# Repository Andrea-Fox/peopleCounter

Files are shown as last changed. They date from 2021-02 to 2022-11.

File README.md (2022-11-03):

# This folder is currently archived

----------------------------------------------------------

# ESP people counter

This repository contains a program (to be flashed, for example on an ESP32, using the Arduino IDE) which allows to create a sensor capable of detecting people going in and out of a room. It works using the VL53L1X sensor by ST Microelectronics. The passage detection is then shared through the MQTT protocol and the count of the people in the room is done directly on other platform such as Home Assistant (see the dedicated file for a smooth integration in Home Assistant).

## Idea behind the algorithm

The code contains an adaptation of the program  [STSW-IMG10](https://www.st.com/en/embedded-software/stsw-img010.html) (developed by ST Microelectronics), written using the [Sparkfun library for VL53L31X](https://learn.sparkfun.com/tutorials/qwiic-distance-sensor-vl53l1x-hookup-guide/all).  

**The library used is from SparkFun and is made for [their sensor](https://www.sparkfun.com/products/14722), however the same code can also be used alongside the [Pololu VL53L31X sensor](https://www.pololu.com/product/3415).**

The sensor uses the time of flight (ToF) of invisible, eye-safe laser pulses to measure absolute distances independent of ambient lighting conditions  and target characteristics like color, shape, and texture (though these  things will affect the maximum range).  Something is detected in a certain zone, when the distance read by the sensor os lower than the corresponding threshold. 

The idea behind the main algorithm counting for people is the following: after defining two different zones, a passage (entrance or exit) is registered only when:

1. a person is detected in the first zone
2. a person is detected in both zones simultaneously
3. a person is detected in the second zone
4. no person are detected in both zones

Then, depending on which are the first and the second zone, the movement will be either registered as an entrance or an exit. 

## Hardware

### Sensor

As previously stated, the library used to write the code is built for the [Sparkfun Distance Sensor](https://www.sparkfun.com/products/14722), but also works using the [Pololu VL53L31X sensor](https://www.pololu.com/product/3415).
It probably should also work with other VL53L1X sensors, however I've never tried it.

### Board

The following tables contain the necessary wire connections, when using certain boards.

#### 5V boards

(including Arduino Uno, Leonardo, Mega)

```
Arduino   VL53L1X board
-------   -------------
     5V - VIN
    GND - GND
    SDA - SDA
    SCL - SCL
```

The Pololu sensor can also be connetced to 3.3V boards, such as the Arduino Due.

Clearly, to use the MQTT functionalities one has to use a board which supports WiFi connection, such as ESP32: in this case, the connections are the following:

#### ESP32

```
                    ESP32   VL53L1X board
-------------------------   -------------
                      3V3 - VIN
                      GND - GND
     SDA (pin 42, GPIO21) - SDA
     SCL (pin 39, GPIO22) - SCL
```
The sensors from Pololu and Adafruit can also be connected to the 5v pin (VIN)
#### ESP8266
It is also possible to use an ESP8266, using, for example, the following connections: (in that case, use the code specific for this board)
```
                  ESP8266   VL53L1X board
-------------------------   -------------
                      3V3 - VIN
                      GND - GND
                       D2 - SDA
                       D1 - SCL
```

## How to adapt the code to your case

The sensor can be mounted on the top of a door frame or on the side. It has been observed that if the door is wide it is more convenient to mount the sensor on the side.

### WiFi information

In order to connect to the WiFi, one has to specify the name of the WiFi network, its password, the MQTT broker address and ots port, the MQTT username and the corresponding password. All this values have to inserted at the beginning of the code, in the corresponding lines.

### Parameters one might want to set

In the first few lines of the code in the main folder, there are a few parameters which can be modified: (in the parentheses, are indicated the default values)

- `devicename` (name_for_this_device)
- `threshold_percentage` (80)
- `update_raw_measurements` (false)
- `advised_orientation_of_the_sensor` (true)
- `save_calibration_result` (true)
- `short_distance_threshold` (1300)
- `delay_between_measurements_long` (50)
- `time_budget_in_ms_long` (50)
- `delay_between_measurements_short` (20)
- `time_budget_in_ms_short` (20)

Some parameters areavailable only in the ESP32 version. 

#### Name of the device
It indicates the room in which the sensor is going to be positioned. It will simplt change the MQTT topics and will help when multiple sensors are placed around the house.

#### Threshold percentage

After mounting the sensor, it detects automatically the height at which it is situated. When the sensor is working, a person is detected if the distance measured is below a certain threshold, hence defining the right thresholds is pivotal to guarantee a correct functioning of the whole system. It has been observed that having as threshold a value which is 80% of the distance measured in general produces good results, however one might observe that is his sistuation another value of the threshold is better.

#### Update raw measurements
In the initial phase, or when debugging, it can be useful to read the distance measured every 100 ms by the sensor, however in general thish is not useful and produces an useless cinsumption of the resources.
This value has to be set to true if one wants to read the distances measured, however the advice is to hold that to `false`.  
One can change this value through MQTT using the command "update_raw_measurement".

#### Advised orientation of the sensor
This value is going to deterin the center of each zone of detection and has to be true if the sensor is positioned as in the following image:
<p float="left">
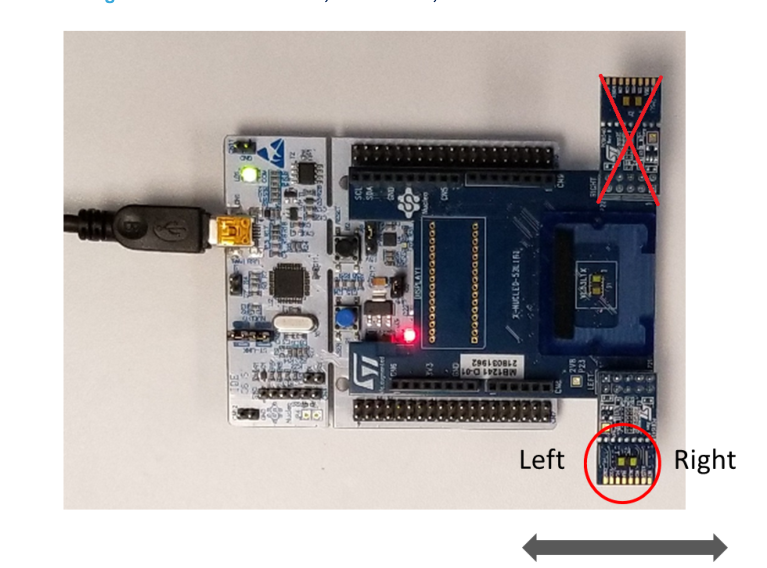
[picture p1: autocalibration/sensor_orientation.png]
  
</p>

The arrow indicates the direction of the people passing under the sensor.

#### Save calibration result
If this value is true, then the results of the calibration of the zones are going to be stored in the EEPROM memory, hence if the ESP is turned off no data is going to be lost. If false, every time the sensor is turned on, a new calibraion is launched, however that is useless if the sensor is always in the same position.
A recalibration can still be called using the MQTT command (see the integration with Home Assistant file)

#### Short distance threshold
When the distane measured in one of the zones is below this threshold (exoressed in millimeters) the sensor uses the short distance mode, which allows more frequent measurements and better performances. The VL53L1X sensor supports short distance mode only if the distance is below 1300 mm

#### Measurements time parameters
These parameters set the time the sensor takes to do a measurements (in milliseconds) and the following delay between two different measurements. The user can define two different values: one for the longRange mode and one for the shortRange mode

### Additional information

Additional information about the parameters used in the code can be found in the `additional_information.md` file in the `manual_configuration` folder

### How to invert the two zones
If you observe that when you get in a room the number of people inside it decreases, while it increases when you get out it means that the values of the centers are inverted. to solve this issue, you can simply invert the values 1 and 2 in the automations which regulate the number of people in the `integration_with_home_assistant.md` file.

### Issues due to sunlight
As stated in the datasheet from the creators of the sensor, the VL53L1X has (much) less accuracy when there is a lot of light. Unfortunately it is not possible to eliminate such issue

## Case for the sensor

In the `case` folder you can find an several stl files created by @noxhirsch for a case that fits both the ESP and the VL53L1X sensor.

## Discord server

If you want to discuss about the idea of finding the ultimate room presence sensor, feel free to join the dedicate Discord server, created by @DutchDeffy: https://discord.gg/65eBamz7AS

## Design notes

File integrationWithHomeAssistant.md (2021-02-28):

# Integration with the Home Assistant
These example of automations are based on the topics defined in the file with automatic calibration called either `people_counter_esp32.ino` or `people_counter_esp8266`. If you are using the file in the `manual calibration` folder, you will have to change the topics.

In order to integrate this sensor inside your Home Assistant setup, the following chunks of code need to be added to the appropriate files.

**We will have to define an input number**, that simply will count the number of people inside the room. It will be called `input_number.people_in_the_room`

The parameter DEVICENAME has to be set in the code, at the beginning of it.

#### automations.yaml

We now need to define two automations that will allow us to understand when someone is getting in or out of the room. This first one will take account of the first case.

```yaml
- alias: 'Person entering the room'
  description: ''
  id: 'person_entering_the_room' # unique id here
  trigger:
     - platform: mqtt
       topic: "people_counter/DEVICENAME/counter"
       payload: '1'
  action:
     - service: input_number.increment
       data: 
            entity_id: input_number.people_in_the_room
  mode: single

```

The following automation will take account of the case of someone exiting the room:

```yaml
- alias: 'Person exiting the room'
  description: ''
  id: 'person_exiting_the_room' # unique id here
  trigger:
     - platform: mqtt
       topic: "people_counter/DEVICENAME/counter"
       payload: '2'
  action:
     - service: input_number.decrement
       data: 
            entity_id: input_number.people_in_the_room
  mode: single

```

If you are using a version of HA >=113.0, you can use only the followning automation (suggested by @noxhirsch) to handle the number of people in the room:
```yaml
alias: Person Counter
trigger:
  - platform: mqtt
    topic: people_counter/DEVICENAME/counter
action:
  - choose:
      - conditions:
          - condition: template
            value_template: '{{ trigger.payload == "1" }}'
        sequence:
          - service: input_number.increment
            entity_id: input_number.people_counter
      - conditions:
          - condition: template
            value_template: '{{ trigger.payload == "2" }}'
        sequence:
          - service: input_number.decrement
            entity_id: input_number.people_counter
mode: single
```

Finally, this automation will turn on a light when there is at least one person in the room:

```yaml
- alias: 'Turn on the light'
  description: ''
  id: 'turn_on_the_light' # unique id here
  trigger:
    - entity_id: input_number.people_in_the_room
      above: '0'
      platform: numeric_state
  action:
    - service: switch.turn_on
      entity_id: switch.light_in_the_room
  mode: single
```

and this one turns the light off when the last person gets out of the room:

```yaml
- alias: 'Turn on the light'
  description: ''
  id: 'turn_on_the_light' # unique id here
  trigger:
    - entity_id: input_number.people_in_the_room
      below: '1'
      platform: numeric_state
  action:
    - service: switch.turn_off
      entity_id: switch.light_in_the_room
  mode: single

```

One might also define an automation for recalibrating the thresholds every day at a certain time (let's say 4 am):
```yaml
- alias: 'Recalibrate threshold'
  description: ''
  id: 'recalibrate_threshold' # unique id here
  trigger:
    - at: '04:00:00'
      platform: time
  action:
    - service: mqtt.publish
      data:
        topic: people_counter/DEVICENAME/receiver
        payload_template: "new_threshold"
  mode: single

```

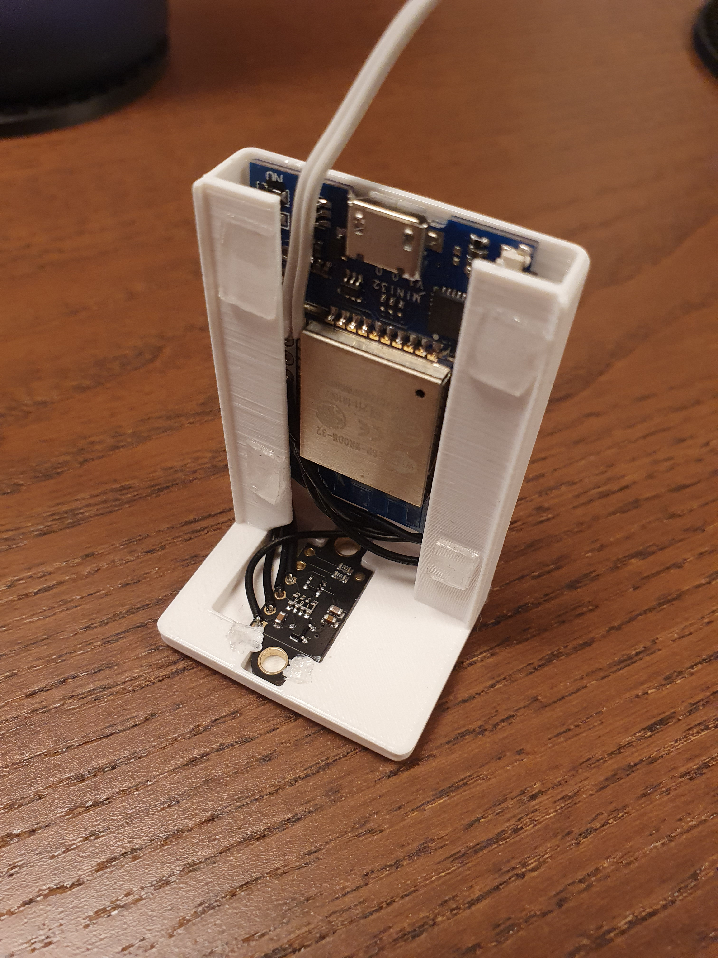
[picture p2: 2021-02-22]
case/case_image.jpg

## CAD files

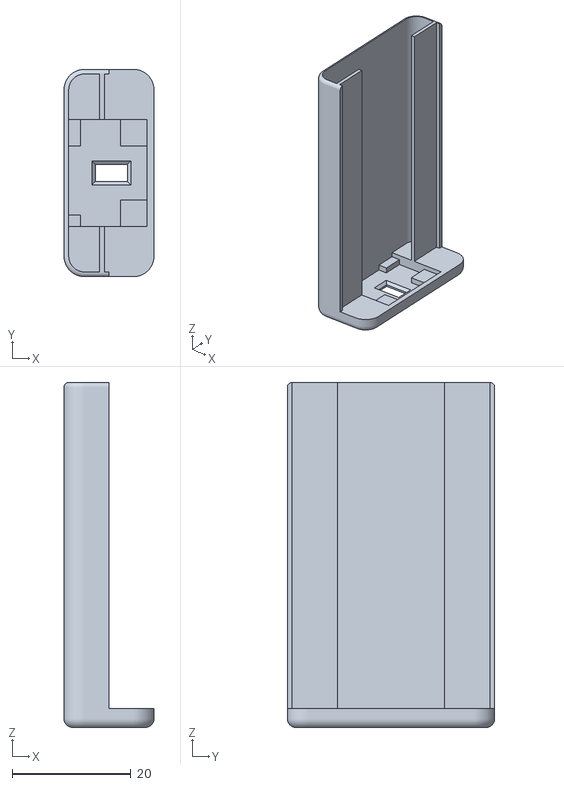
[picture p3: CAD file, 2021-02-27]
case/Person_Tracker_Pololu_Fat.stl
15.2 x 35.0 x 58.2

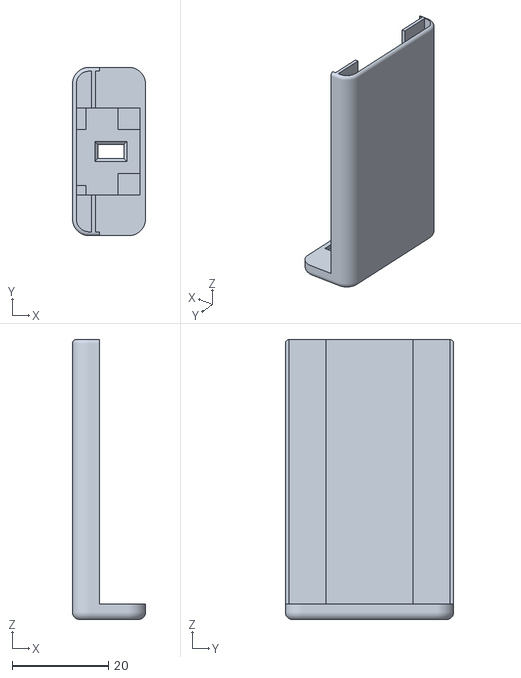
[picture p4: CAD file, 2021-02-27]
case/Person_Tracker_Pololu_Slim.stl
15.2 x 35.0 x 58.2

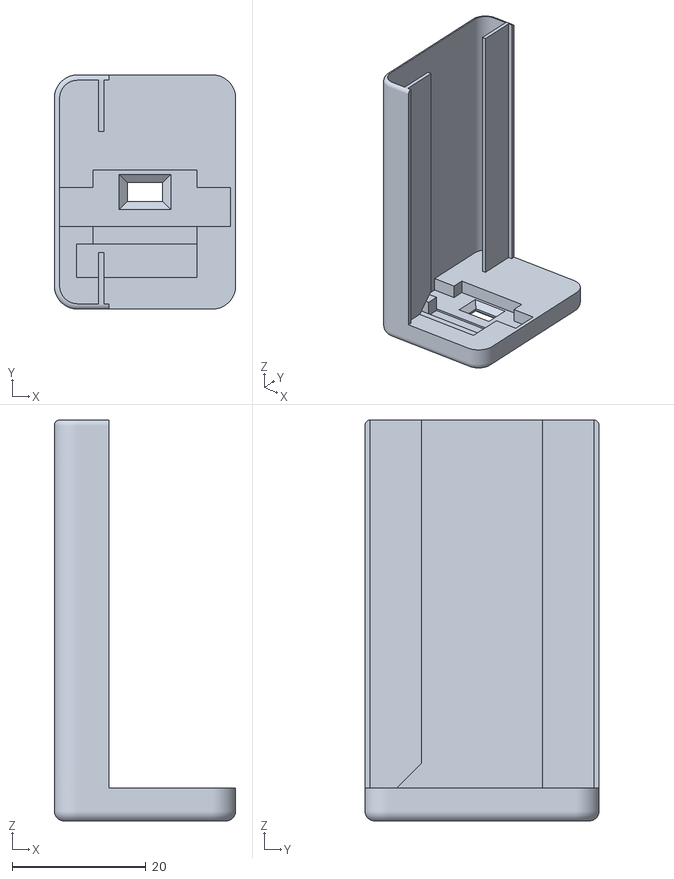
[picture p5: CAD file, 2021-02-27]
case/Person_Tracker_Aliexpress.stl
27.1 x 35.0 x 59.9

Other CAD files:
case/People Counter Aliexpress.f3d
case/People Counter Pololu.f3d

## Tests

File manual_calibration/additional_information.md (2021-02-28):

## Additional informations about the parameters

#### Relevant area

In order to find the correct distance, the sensor creates a 16x16 grid and the final distance is computed by taking the average of the distance of the values of the grid; to perform our task, one has to create two zones, by defining two different Region of Interest (ROI) inside this grid. Then the sensor will measure the two distances in the two zones and will detect any presence. 

However, the algorithm is very sensitive to the slightest modification of the ROI, regarding both its size and its positioning inside the grid.

In the original code, developed by ST Microelectronics, the values for the parameters are the following:

- `ROI_width = 8`
- `ROI_height = 16`
- `center = {167,231}`
however, I've noticed better performances with the values suggested in the code above.

Be careful that both `ROI_width` and `ROI_heigth` have to be at least 4. The center of the ROI you set is based on the table below and the optical center has to be set as the pad above and to the right of your exact center:

| 128  | 136  | 144  | 152  | 160  | 168  | 176  | 184  | 192  | 200  | 208  | 216  | 224  | 232  | 240  | 248  |
| ---- | ---- | ---- | ---- | ---- | ---- | ---- | ---- | ---- | ---- | ---- | ---- | ---- | ---- | ---- | ---- |
| 129  | 137  | 145  | 153  | 161  | 169  | 177  | 185  | 193  | 201  | 209  | 217  | 225  | 233  | 241  | 249  |
| 130  | 138  | 146  | 154  | 162  | 170  | 178  | 186  | 194  | 202  | 210  | 218  | 226  | 234  | 242  | 250  |
| 131  | 139  | 146  | 155  | 163  | 171  | 179  | 187  | 195  | 203  | 211  | 219  | 227  | 235  | 243  | 251  |
| 132  | 140  | 147  | 156  | 164  | 172  | 180  | 188  | 196  | 204  | 212  | 220  | 228  | 236  | 244  | 252  |
| 133  | 141  | 148  | 157  | 165  | 173  | 181  | 189  | 197  | 205  | 213  | 221  | 229  | 237  | 245  | 253  |
| 134  | 142  | 149  | 158  | 166  | 174  | 182  | 190  | 198  | 206  | 214  | 222  | 230  | 238  | 246  | 254  |
| 135  | 143  | 150  | 159  | 167  | 175  | 183  | 191  | 199  | 207  | 215  | 223  | 231  | 239  | 247  | 255  |
| 127  | 119  | 111  | 103  | 95 | 87 | 79 | 71 | 63 | 55 | 47 | 39 | 31 | 23 | 15 | 7 |
| 126  | 118  | 110  | 102  | 94 | 86 | 78 | 70 | 62 | 54 | 46 | 38 | 30 | 22 | 14 | 6 |
| 125  | 117  | 109  | 101  | 93 | 85 | 77 | 69 | 61 | 53 | 45 | 37 | 29 | 21 | 13 | 5 |
| 124  | 116  | 108  | 100  | 92 | 84 | 76 | 68 | 60 | 52 | 44 | 36 | 28 | 20 | 12 | 4 |
| 123  | 115  | 107  | 99 | 91 | 83 | 75 | 67 | 59 | 51 | 43 | 35 | 27 | 19 | 11 | 3 |
| 122  | 114  | 106  | 98 | 90 | 82 | 74 | 66 | 58 | 50 | 42 | 34 | 26 | 18 | 10 | 2 |
| 121  | 113  | 105  | 97 | 89 | 81 | 73 | 65 | 57 | 49 | 41 | 33 | 25 | 17 | 9 | 1 |
| 120  | 112  | 104  | 96 | 88 | 80 | 72 | 64 | 56 | 48 | 40 | 32 | 24 | 16 | 8 | 0 |

#### Threshold distance

Another crucial choice is the one corresponding to the threshold. Indeed a movement is detected whenever the distance read by the sensor is below this value. The code contains a vector as threshold, as one (as myself) might need a different threshold for each zone.

The SparkFun library also supports more formats for the threshold: for example one can set that a movement is detected whenever the distance is between two values. However, more information for the interested reader can be found on the corresponding page.

With the updated code (however only for esp32 at the moment) the threshold is automatically calculated by the sensor. To do so it is necessary to position the sensor and, after turning it on, wait for 10 seconds without passing under it. After this time, the average of the measures for each zone will be computed and the thereshold for each ROI will correspond to 80% of the average value. Also the value of 80% can be modified in the code, by editing the variable `threshold_percentage`

The calibration of the threshold can also be triggered by a MQTT message. An example for doing so is in the file `integration_with_home_assistant.md`.

## Useful links

[PDf file with more information about the algorithm](https://www.google.com/url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): this PDF is an in-depth explanation of the algorithm and contains technical details about the sensor

[SparkFun library guide](https://learn.sparkfun.com/tutorials/qwiic-distance-sensor-vl53l1x-hookup-guide/all) with more information about the functions used in the code

[MQTT with ESP32 tutorial](https://iotdesignpro.com/projects/how-to-connect-esp32-mqtt-broker)

[This article](https://lastminuteengineers.com/esp32-ota-updates-arduino-ide/) gives additional information about the OTA updates in Arduino using the Arduino IDE.

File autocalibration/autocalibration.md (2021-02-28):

In this file, it will be explained the idea behind the autocalibration of the zones

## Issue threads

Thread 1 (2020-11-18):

Count People at two entrance

TheMBeat, 2020-11-18:
Hello @Andrea-Fox ,

I would like to use your code to count people on a staircase. This would require using two sensors on an ESP32, as people can leave the stairs at the beginning and end. The use of two sensors is possible after a research with i2c.
Can the VL53L0X also be used instead of the VL53L1X?

Best regards TheMBeat

Andrea-Fox, 2020-11-18:
Hi, @TheMBeat,
unfortunately I don't think that the code would work using the VL53L0X sensor, as it would require to use its own library.  Moreover, the idea behind the algorithm exploits the fact that there exist multiple zones (the region of interest) and I think that it is impossible to obtain those using a VL53L0X sensor.
Best regards,
Andrea Fox

TheMBeat, 2020-11-18:
Hello @Andrea-Fox ,
Do the two sensors differ not only in the distance that can be measured? Therefore I thought it was also possible with the VL53L0X.
Best regards.
TheMBeat

burton666, 2020-11-18:
No there are many differences between those two sensors, ROI (Region of interest) is one of them. You can read more [here](https://blog.st.com/vl53l1x/)

TheMBeat, 2020-11-18:
Ahh, okay.
If I have two VL53L1X, would it still be possible to count people at two doors?

burton666, 2020-11-18:
Yes, but I am pretty sure that you need one separate esp for each sensor. The sensors/code  doesnt care where you place them as they only count persons leaving or entering under/beside them. In your case the stairs would be the same as any other room and the logic will have to be executed by Home Assistant (or any other home automation system)

Andrea-Fox, 2020-11-18:
As @burton666 said, you can just place one sensor at the beginning of the stairs and one at the end and then treat the stairs as a room. Then, both sensor will register the people going in and out of the room (the stairs) and through Home Assistant you can manage the number of people in the room (and the lights in the stairs).

TheMBeat, 2020-11-19:
Hello XXX,
thanks for the quick answers and your help. I will probably order the sensors and try a little bit.
Have nice days and stay healthy.

Closed 2020-11-19.

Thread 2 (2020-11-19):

Possible to use ESP8266 ?

burton666, 2020-11-19:
Is it possible to use an ESP8266 instead of a ESP32 or do you need the extra processing power that the ESP32 has ?

Andrea-Fox, 2020-11-19:
In theory it should work also for the ESP8266 as all the connections needed are there, but unfortunately I've never tried it. In any case, I don't think that the processing power needed is too high to handle for the ESP8266.
If you succeed in using it with an ESP8266, please tell me so I can update the read.me file

Andrea-Fox, 2020-11-26:
I've added a new code specific for ESP8266 (just a slight modification of the original file). You can find it as peopleCounterESP8266.ino in the main folder

Closed 2020-11-26.

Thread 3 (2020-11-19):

Wifi connection issues

burton666, 2020-11-19:
I have tried different ESP32s, different USB-cables, and tried connecting to several networks (2.4Ghz). But I only get the "Sensor online" -message. Then dots, but it never connects to any wifi. Is there any special procedure for connecting to a wifi network besides specifying the sid and password ?

Andrea-Fox, 2020-11-19:
Hi, I've observed that if you don't put into the code also the informations about the mqtt server (its IP address, the username and the pasword) for some reasons it cannot connect to the WiFi. Maybe that is the reason it doesn't connect

burton666, 2020-11-19:
Ok, I am not using any password for my mqtt server so I just used blank username/password in the sketch. I tried removing them completly from the client and then it worked.

But my next problem is that the sensor shows up in my mqttserver-logfile but after a few seconds I get this error:
`
1605794760: New client connected from 192.168.0.205 as PeopleCounterESP32Client-3a24 (p2, c1, k15).
1605794767: Client PeopleCounterESP32Client-3d85 has exceeded timeout, disconnecting.
`
Do you have any ideas of what is wrong ?

Andrea-Fox, 2020-11-19:
Maybe this [thread](https://github.com/mqttjs/MQTT.js/issues/381) might help you. However, I've never seen this kind of problem (fortunately) and I cannot understand where it comes from

burton666, 2020-11-19:
Sorry, I am stupid. I had previously just inserted the pin-headers into the esp32 but had not soldered them. The pins felt solid when picking up the esp32 but the electric connection was very sketchy 😄

kentwk, 2020-11-26:
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
Any Suggestion for my error msg? i try around 100 times still same error...

burton666, 2020-11-26:
Just a guess, if you are trying to connect to a 5ghz WiFi-network switch to a 2.4ghz network instead

kentwk, 2020-11-26:
> Just a guess, if you are trying to connect to a 5ghz WiFi-network switch to a 2.4ghz network instead. Otherwise I got the same error when something was wrong with the mqtt settings.

This is 2.4ghz wifi...i saw u same case with me...how u fixed this problem?

burton666, 2020-11-26:
My problem was that I did not have user/pass for my mqtt server but still had the mqtt_user/pass set to "". I solved it by removing the variables and all usage of them. So I guess your problem also is related to the mqtt server in some way.

kentwk, 2020-11-26:
> My problem was that I did not have user/pass for my mqtt server but still had the mqtt_user/pass set to "". I solved it by removing the variables and all usage of them. So I guess your problem also is related to the mqtt server in some way.

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
i remove related about MQTT setting, but also same error...after type sensor online then keep dot dot dot....owner pls help me figure out what is my problem....pls....

burton666, 2020-11-26:
Ok, i just deleted:
`mqtt_user` and `mqtt_pass` variables in the begining

and after that removed those variables from:
`if (client.connect(clientId.c_str(),mqtt_user,mqtt_pass))`

and ofcource your mqtt server must be configured to be able to access without user/password

Andrea-Fox, 2020-11-26:
I can only suggest you to do what @burton666 described (btw, thank you for your quick answers). The problem you're describing is related to the WiFi.h file and unfortunately I cannot know what causes it.
From your pictures I see that you've setted as device "SparkFun ESP32 Thing", while I've always used ESP32 Dev Module ; maybe your issue is related to that

sotidis, 2020-11-26:
WiFi.begin(ssid, password);
  while (WiFi.status() != WL_CONNECTED)
  {
    delay(5000);
    Serial.print(".");
    WiFi.begin(ssid, password);

Try to increase  delay, it helped me.

kentwk, 2020-11-27:
Finally success to connect MQTT, thanks everyone, i just follow @sotidis solution to fix it. i still have one problem about automation.yaml
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

kentwk, 2020-11-27:
Finally success to connect MQTT, thanks everyone, i just follow @sotidis solution to fix it.

Closed 2020-11-27.

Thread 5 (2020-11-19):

Configure MQTT for HomeAssistant

burton666, 2020-11-19:
Ok, I got some more stupid questions. I have a Zigbee2MQTT USB-Stick in my server and also dockers running a Mosquitto MQTT server and another docker running Home Assistant. The Zigbee2MQTT-usb sends everything to the MQTT server and they show up in Home Assistant in Integrations -> MQTT.

In the Mosquitto log I see:

```
1605812716: New connection from 192.168.0.182 on port 1883.
1605812716: New client connected from 192.168.0.182 as PeopleCounterESP32Client-a164 (p2, c1, k15).
```

But how do I make the device show up in Home Assistant ?
I tried Adding the :
```
sensor:
    - platform: mqtt
      name: "People counter"
      state_topic: "peopleCounter/serialdata/tx"
```

But I get no new devices with or without the sensor added to config.yaml

Andrea-Fox, 2020-11-19:
Have you restarted Home Assistant?

Closed 2021-02-02.

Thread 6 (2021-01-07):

Updated ST algorithm V2

markjones89, 2021-01-07:
Hi @Andrea-Fox

Thanks for this project, I noticed on ST's website that they have released version 2 of there code, from what I can see they have updated the code to include a buffer of measurements to feed into the counting algorithm for better accuracy. This might be of some interest for your project.

https://www.st.com/en/embedded-software/stsw-img010.html

Andrea-Fox, 2021-01-07:
Thank you for the suggestion! I will give a look in the future and see if I'm able to create a similar updated version also for esp32/esp8266

itekhi, 2022-10-19:
Would love to see the V2 update :)
Do you have a V1 example of their code? I could compare them to see what's new.

Andrea-Fox, 2022-11-03:
Hi, I've added in the original_code folder their V1 code which is currently not available on their website

Closed 2022-11-03.

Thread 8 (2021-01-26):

Esphome integration

DutchDeffy, 2021-01-26:
Do you know esphome? It has seamless integration with home assistant. I'm busy on a way to integrate the people counting people concept with the VL53L1X sensor to Esphome. Don't know if it's working this way but here's is the repo: https://github.com/DutchDeffy/esphome_custom_component_VL53L1X_people_counter.

Andrea-Fox, 2021-01-26:
Unfortunately I discovered esphome only a few weeks after creating this project :)
However I'm planning to integrate this idea into that project, as it is much better and would probably reach an higher number of people

DutchDeffy, 2021-02-05:
There’s already a pull request for adding the sensor to Esphome as a component which passsd all the checks and is to be reviewed and checked. The code doesn’t do the algorithm and people counting logic yet. Currently it does do the distance measuring part, which is already really brilliant. Maybe it could help you out. The PR is referenced by #1447 and #916 for the docs.

Andrea-Fox, 2021-02-05:
I will definitely look into it. Thank you for the informations

Closed 2021-02-05.

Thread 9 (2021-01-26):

High power consumption -> not possible to run via battery

LC7894, 2021-01-26:
I measured the power consumption of the sensor and found it to use (on average) 80mA for a setup with an ES8266 NodeMCU. Therefore, using a battery as power source is not suitable except you want to change the battery in very small intervals. This is a problem when there is no outlet nearby or you don't want to use a cord. According to the docs of the sensor it should be possible to use the deep sleep mode of the ESP and wake it up when someone passes the sensor:

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

I just leave this here as a suggestion for further development of the algorithm 🙂 (Maybe I am able to find a solution on my own, but I have to learn a lot about ESP programing until I reach this point)

Andrea-Fox, 2021-01-26:
I know that the consumption are very high, however I wanted to always have the sensor connected to the wifi, in order to minimize the time that passes between passing under the sensor and turning on (or off) the light.
I know that turning on and off the wifi should be almost immediate, however I think that even at that point the consumption given by the VL53L1X sensor and the ESP itself (with wifi off) make it impossible to connect the whole device to a battery and have a long battery life. However, if you manage to create a sensor that works with battery and has a long battery life (at least a few months I would say), let me know

LC7894, 2021-01-26:
The delay between passing the sensor and turning on/off the light is definitely a disadvantage when it comes to turning off the WiFi to save some battery. In addition (as you said) the consumption of the sensor + ESP itself with wifi off is still high. So that is another challenge.

I'll let you know if I managed to create a sensor with a long battery life (long = > 6 months) and a delay that is acceptable. But I see some challenges here so let's see.

avdept, 2021-03-31:
How about to use zigbee instead of wifi? Should use less power

Andrea-Fox, 2021-04-01:
Is there a way to use zigbee with the esp32/esp8266?

profx5015, 2021-05-19:
> Is there a way to use zigbee with the esp32/esp8266?

Here is a library to connect atmega328 with cc2530.
https://github.com/VertorixAU/Vertorix_VT1100_Mini

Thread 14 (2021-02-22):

Code question advised_oriantation_of_the_sensor

noxhirsch, 2021-02-22:
Shouldn't the switch...case for `advised_orientation_of_the_sensor == false` also have `break;`?

```
  if (advised_orientation_of_the_sensor){

    switch (ROI_size) {
        case 4:
          center[0] = 150;
          center[1] = 247;
          break;
        case 5:
          center[0] = 150;
          center[1] = 247;
          break;
        case 6:
          center[0] = 159;
          center[1] = 239;
          break;
        case 7:
          center[0] = 159;
          center[1] = 239;
          break;
        case 8:
          center[0] = 167;
          center[1] = 231;
          break;
      }
  }
  else{
    switch (ROI_size) {
        case 4:
          center[0] = 195;
          center[1] = 60;
        case 5:
          center[0] = 194;
          center[1] = 59;
        case 6:
          center[0] = 194;
          center[1] = 59;
        case 7:
          center[0] = 193;
          center[1] = 58;
        case 8:
          center[0] = 193;
          center[1] = 58;

      }
  }
```

Andrea-Fox, 2021-02-22:
You are completely right. I will edit now. Thank you for noticing that as well

Closed 2021-02-22.

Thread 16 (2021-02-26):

Possible enhancement with 4 ROIs

markjones89, 2021-02-26:
Hi @Andrea-Fox and @noxhirsch, Thanks so much for what you have done here!

I have been thinking of possible ways to make the sensor more accurate on wider doorways.

My thinking behind this is to use more than 2 ROIs but rather use 4 zones of 8x8 two would be in the front zone and two in the back zone. ( Note I haven't had much success with an ROI set to 8 x 16 but 8x8 works well but sometimes misses counts if you approach a doorway from an angle)

I am working on trying to implement this but would be interested in your opinion on the idea?

I was considering two possible ways of implementing this.

option 1: feed the two values from the front zone into the counting algorithm at the same time and the same for the back zone
option 2: feed the lowest measurement reading from the two zones in the front and back into the algorithm.

Thank you
Mark

LC7894, 2021-02-26:
Hi @markjones89,

I also have the issue that the sensor is not always accurate on wider doorways. Until now I was not able to find a more reliable solution.

Your idea with the four ROIs might be a solution to the problem, but unfortunately the VL53L1X sensor is only capable of using two zones and not four (hardware restriction). For this reason your approach will not work in my eyes (correct me if I'm wrong).

noxhirsch, 2021-02-26:
Maybe for wider doorways it's easier to mount them on one side? I did this with my old VL53L0X sensors that I used as simple motion sensors:
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
As far as I remember other people on the Discord server also tried that.

Andrea-Fox, 2021-02-26:
@LC7894 are you sure that you cannot use more than two zones? Because I've never tried and I had no idea of this limitation

@markjones89 I think that the idea should work, however, I'm not sure it would be as precise. The sensor is only able to measure the distance one ROI at a time and each measurement takes up to 100 ms (now it's 50 ms for each measurement and 50 of delay between two different measurements; I've tried to reduce this time but it is not possible, unfortunately). Having 4 zones might not allow being able to detect someone passing under it properly due to the long time that passes between one measurement and the other.
I can suggest you to try putting the sensor on the side of your door; by doing so the width of the door won't be an issue (unless you have a door wider than 4 meters

markjones89, 2021-02-26:
Thank you all, much appreciated the quick feed back. I've also had the idea to make an new version with 2 sensors. I've gone as far as designing a pcb. It's got a few errors in the design but would be happy to share the files. 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

markjones89, 2021-02-27:
Maybe a possible solution for the timing for 4 zones could be to alternate between two front zones Ans two back zones.
Eg zone 1,3 are front zones 2,4 are back zones.

The sensor first checks zone 1 and 2 then swaps to zone 3 and 4, this would still use the same timing bit could check a larger area. I'm going to test it out and see if it makes an improvement.

Thanks all for your comments.
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

Andrea-Fox, 2021-02-27:
I'm not entirely sure of it is going to work, however if you obtain good results let us know. I'm still convinced that putting the sensor on the side of the door is a better idea in this case

hoangtruong2412, 2021-07-30:
hi, is there any specific formula to calculate detection area? I installed the sensor at the door level, my doorway is about 85cm wide. but if I go too close to the sensor or too far it doesn't recognize it, I have to go in the middle of the sensor door frame to recognize it relatively well. 10 times passing but 4 to 5 times the sensor does not recognize it is a sad thing.

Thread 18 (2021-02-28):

ESPHome compatible sketch?

drageloth, 2021-02-28:
Hello,

Sorry for declaring it as an issue, it's more of a question. Will there be a file available for ESPHome? It's way easier, especially for HomeAssistant to integrate automatically. Thanks!

Andrea-Fox, 2021-02-28:
Unfortunately I'm not able to integrate this idea inside ESPHome. Me (and other people) have tried to create an integration, as we understand that it would be much easier and it would reach a broader audience, however we found that creating an ESPHome integration is very complex.
You can find more informations [here](https://github.com/esphome/esphome/pull/1447) and if you are able to create the integration (or know someone who is able to), it would help a lot

drageloth, 2021-03-01:
I haven't the slightest idea to be honest, but could [https://github.com/diplix/esphome-configuration](url) help with that? Seems it's already for ESPHome, though it will need some files directly imported to the ESPHome folder. But it's a start. The problem with diplix is some false negatives with people with different heights (I'm getting regocgnised at all times, wife at 70%)

Andrea-Fox, 2021-03-01:
If I'm understanding correctly, the repository you linked uses the VL53L1X sensor only to count people sitting on a bathroom. Am I correct? Because the code in this repository is made for counting people entering (or getting out) of a room

drageloth, 2021-03-01:
> If I'm understanding correctly, the repository you linked uses the VL53L1X sensor only to count people sitting on a bathroom. Am I correct? Because the code in this repository is made for counting people entering (or getting out) of a room

It has this option too, but the main one is people counting sensor. The sketch exposes a multisensor. Picture attached to see for the counting sensor.
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
In main terms it's good. It can track entry and exit(but only exposes a number of people inside, not actual entry or exit), it can track if someone is standing on the door and if the person doesn't enter, it doesn't count as entry and has some other bits and pieces (distance sensor, restart etc)
The only big downside I've found is with the wife as she's 1.75m(I'm 1.93m) and sometimes the sensor doesn't count either exit or entry, making the people_count sensor wrong(eg 1 person inside when noone is).

Andrea-Fox, 2021-03-01:
What I have observed is that in cases such as the one you explained, where only taller people are identified, the error is due to a wrong value of a threshold that defines if someone is passing under the door. It probably is higher than it should be.
However, thank you for making me discover that repository. It might be useful in the future

drageloth, 2021-03-01:
Thanks too! Will keep an eye on this repo too!

Closed 2021-03-01.

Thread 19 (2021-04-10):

Pls help check my hardware support anot?

kentwk, 2021-04-10:
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

Pls help check my hardware support anot? Because I walk from which way result keep zero.

Andrea-Fox, 2021-04-11:
The connections seem correct. Maybe the issue is the sensor. First of all, is it a VL53L1X sensor? If so, in general there is some sort of cover on the sensor. Try removing that.
If then it still doesn't work, try connecting it to a 5v pin

kentwk, 2021-04-12:
> The connections seem correct. Maybe the issue is the sensor. First of all, is it a VL53L1X sensor? If so, in general there is some sort of cover on the sensor. Try removing that.
> If then it still doesn't work, try connecting it to a 5v pin

1)Yes...is VL53L1X-V2
1)Soft cover removed
2)Tried use 5v pin...not working

Do u mind show your sensor?

Andrea-Fox, 2021-04-18:
Then I really don't know which is the problem.
Maybe the sensor is defective

kentwk, 2021-04-18:
> Then I really don't know which is the problem.
> Maybe the sensor is defective

but i have tried few sensor also same...izzit u sensor same with me?if working izzit serial monitor result 0 will change 1 then 2?

Andrea-Fox, 2021-04-22:
Currently I'm using a sensor from Pololu, which is not the one you're using.

When working, in the signal monitor you should read the distance measured by the sensor (in your case, unfortunately, always equal to 0)

kentwk, 2021-05-02:
> Currently I'm using a sensor from Pololu, which is not the one you're using.
>
> When working, in the signal monitor you should read the distance measured by the sensor (in your case, unfortunately, always equal to 0)

Do u mind screen shot your serial monitor?

kentwk, 2021-05-17:
> Currently I'm using a sensor from Pololu, which is not the one you're using.
>
> When working, in the signal monitor you should read the distance measured by the sensor (in your case, unfortunately, always equal to 0)

After soldering sensors working.TQ
i use manual_calibration can count people, when using autocalibration no working...may i noe using autocalibration what mqtt topic should i write?

Andrea-Fox, 2021-05-17:
If you are using the code in the file called `people_counter_esp32.ino` or the one in `people_counter_esp8266.ino`, you have to subscribe to the topic `people_counter/NAME_OF_THE_ROOM/counter`, while if you want to read the distance you have to subscribe to the topic `people_counter/NAME_OF_THE_ROOM/distance`.
To specify the name of the room, you have to change the code in the line indicated in the file

sanderlv, 2021-05-18:
same issue maybe here...
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

successfully flashed but not connecting to wifi and no serial logging in arduino IDE? I do get some on ither serial monitor
```
Using 'COM16' as serial port.
Showing logs:
[19:39:12]ets Jun  8 2016 00:22:57
[19:39:12]
[19:39:12]rst:0x1 (POWERON_RESET),boot:0x13 (SPI_FAST_FLASH_BOOT)
[19:39:12]configsip: 0, SPIWP:0xee
[19:39:12]clk_drv:0x00,q_drv:0x00,d_drv:0x00,cs0_drv:0x00,hd_drv:0x00,wp_drv:0x00
[19:39:12]mode:DIO, clock div:1
[19:39:12]load:0x3fff0018,len:4
[19:39:12]load:0x3fff001c,len:1216
[19:39:12]ho 0 tail 12 room 4
[19:39:12]load:0x40078000,len:10944
[19:39:12]load:0x40080400,len:6388
[19:39:12]entry 0x400806b4
[19:39:12]E (58) psram: PSRAM ID read error: 0xffffffff
[19:39:12][19:39:12]
[19:39:12]rst:0xc (SW_CPU_RESET),boot:0x13 (SPI_FAST_FLASH_BOOT)
[19:39:12]configsip: 0, SPIWP:0xee
[19:39:12]clk_drv:0x00,q_drv:0x00,d_drv:0x00,cs0_drv:0x00,hd_drv:0x00,wp_drv:0x00
[19:39:12]mode:DIO, clock div:1
[19:39:12]load:0x3fff0018,len:4
[19:39:12]load:0x3fff001c,len:1216
[19:39:12]ho 0 tail 12 room 4
[19:39:12]load:0x40078000,len:10944
[19:39:12]load:0x40080400,len:6388
[19:39:12]entry 0x400806b4
[19:39:12]E (59) psram: PSRAM ID read error: 0xffffffff
```

kentwk, 2021-05-19:
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

Maybe u can check few things
1)void setup_wifi()
{
  WiFi.begin(ssid, password);
  while (WiFi.status() != WL_CONNECTED)
  {
    delay(5000);
    Serial.print(".");
    WiFi.begin(ssid, password);
  }
}

***Delay from 500 change to 5000***

2)Serial monitor set 9600baud
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

sanderlv, 2021-05-19:
Serial monitor was 9600 👍 but I can not get any output?
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

I changed the 500 to 5000 and it comes alive now... will proceed further with homeassitsant integration etc.

thanks!!

kentwk, 2021-05-19:
Make sure to fill in correct information.

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

sanderlv, 2021-05-19:
Yes, that is correct because I am getting mqtt information:
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

Oh... for my sensor orientation? Do you happen to know like below:
https://github.com/Andrea-Fox/peopleCounter/blob/master/autocalibration/sensor_orientation.png

I have a VL53L1X

kentwk, 2021-05-19:
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

no...I use the manual calibration counting people is working...if using auto calibration no working, no matter what i change MQTT topic also same.

sanderlv, 2021-05-19:
for an ESP32 what would I have to use?

https://github.com/Andrea-Fox/peopleCounter/tree/master/manual_calibration

kentwk, 2021-05-19:
peopleCounter.ino

sanderlv, 2021-05-19:
Hm... that looks complicated for now. i want to try with auto first. I do not see any change on the mqtt tpoic people_counter/tof_people/counter... I do see continuous change on the people_counter/tof_people_ard/distance topic... any tips/suggestion?

kentwk, 2021-05-19:
**Manual Calibration Setting**
1)double-check u serial monitor working anot...if same with my screenshot mean working.then u can next step
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

2)Go Homeassistant-Congfiguration-Helpers-Add Helper
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

3)Go Homeassistant-Files Editor-automations.yaml-add below these script
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

4)Done
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

kentwk, 2021-05-19:
u using manual calibration or auto calibration?

**Follow this Topic**
topic: "peopleCounter/serialdata/tx"

sanderlv, 2021-05-19:
Auto

kentwk, 2021-05-19:
> Auto

u try using manual...because auto calibration also no working for me.

sanderlv, 2021-05-19:
Sorry but I have read that and I do not know how to start with that manual calibrarion

kentwk, 2021-05-19:
> Sorry but I have read that and I do not know how to start with that manual calibrarion

just flash the manual calibration files...then follow my step.

kentwk, 2021-05-20:
u forgot change wifi delay?

void setup_wifi()
{
WiFi.begin(ssid, password);
while (WiFi.status() != WL_CONNECTED)
{
delay(5000);
Serial.print(".");
WiFi.begin(ssid, password);
}
}

Delay from 500 change to 5000

sanderlv, 2021-05-20:
Don't know how that happened... I did thought I checked it, but probably not well enough.. I get now:
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

Andrea-Fox, 2021-05-20:
Hi, what you are seeing in your last message is the correct behavior. The topic in `peopleCounter/serialdata` is updated only whenever a passage is detected.
A passage is detected whenever the array of 4 numbers (the one which is in general 0000) is either 0132 or 0231

kentwk, 2021-06-04:
Let me conclude my topic...just my soldering problem. TQ

Closed 2021-06-04.

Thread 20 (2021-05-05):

ESP32 & VL53L3CX

mottibz, 2021-05-05:
Hi, I would like to implement the code using an ESP32 with the VL53L3CX newer sensor. Can you help? Thanks a lot!!!

Andrea-Fox, 2021-05-06:
Unfortunately I've never worked with that sensor and I do not know it's functionalities. Right now I'm a little busy, but maybe in the future I will look into the VL53L3CX and release a new version of the people counting algorithm which uses it

mottibz, 2021-05-06:
Hi @Andrea-Fox, Thanks for your reply. I will highly appreciate any help. Will continue to investigate and report if I find something useful.

Manuel-Freitas, 2021-08-24:
I would like to implement the code using an ESP32 cam with the VL53L1X sensor. Can you help? Thanks

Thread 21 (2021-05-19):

counter = 1, but never 2

sanderlv, 2021-05-19:
Starting a new topic here.

I used:
people_counter_esp32.ino
the name of my sensor is `tof_people_ard`

Changed the value 500 to 5000 for wifi timeout.

The ESP32 is succesfully conected to WiFi and MQTT. I can see the topic realtime changing for:
`people_counter/tof_people_ard/distance`

I do not see any updates for the counter in topic:
`people_counter/tof_people_ard/counter`

It did work 1 time hower.

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

In above image you can see the MQTT realtime going and on some moment I place my hand before the sensor.

the standard config as in the ino is in my compiled upload. And no matter what I try to place the sensor it counts 2... so the home assistant counter is never updated.

Any help appreciated!

Andrea-Fox, 2021-05-20:
The array of 4 elements is the one which detects if a passage is detected.
The counter topic sends a message (either 1 or 2) only whenever the array has values 0132 or 0231. This can happen only when this happens:
1) something is detected in zone A but nothing is in zone B (at this moment the array has value 0100 or 0200)
2) something is detected in both zones  (0130 or 0230)
3) something is detected in zone B but nothing is in zone A (0132 or 0231)
4) nothing is detected in both zones

If you want to simulate the passage with your hand you have to move slowly (the same speed when you are walking). Moreover, try changing the value of the threshold percentage, as it might be too high for your case

kentwk, 2021-06-06:
// this value has to be true if you don't need to compute the threshold every time the device is turned on
static bool save_calibration_result = false;

**Default value is false...try set to true, then will working.**

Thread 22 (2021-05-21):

install for esp8266

elzershark, 2021-05-21:
unfortunately I don't understand how to set up. What exactly do you have to do? how do  save that?
what is update raw measurements?
what is the mqtt command? true / false?
or update_raw_measurement?
I have install  the firss "people_counter_esp8266.ino". the distance is displayed in the serial monitor. but how do I adjust it now so that he also recognizes when someone goes in or out? I don't see any settings?
this value has to be true if you don't need to compute the threshold every time the device is turned on? how do i save the threshold? how do i find out? where do I save it?

the only thing that is displayed in mqtt is:
mqtt = people_counter/Zaeler/distance = "150	 zona = 0	0000 "
people_counter/Zaeler/receiver =  " "
what do i do with it?
where are the people counted? where is it displayed?
 i have a VL53L1X

have calibration result
If this value is true,

what is value true?
what do you have to do there?

The only thing you can see in the serial monitor is the distance that the sensor is measuring. otherwise nothing happens.

elzershark, 2021-05-21:
zones_calibration

Closed 2021-05-21.

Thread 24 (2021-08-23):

Feature request: Use a single MQTT publisher topic and ArduinoJson.h

DutchDeffy, 2021-08-23:
Hi Andrea,

Here I'm with a suggestion how the code could be improved or functionality can be added to your code. I thought of using a single MQTT topic and publish all the data in json format to that. Instead of using 3 topics. That way configuring can be a bit more easy. I have already something set up already. The idea is of using global variables instead of passing everything data related as a parameter to specific functions. You would need to define those variables. So, for example.

```
/******************************** VARIABLES FOR 'CARRYING' THE DATA *******************************/

String Passage_Event;

uint16_t Distance;

int LocalPeopleCount;
```

The general publish function like this

```
void publishData(){
  StaticJsonDocument<300> doc;

  doc["passage_event"] = Passage_Event;

  JsonObject distance = doc.createNestedObject("distance");
  distance["zone"] = Zone;
  distance["measurement"] = Distance;

  doc["local_people_count"] = LocalPeopleCount;

  char buffer[300];
  serializeJson(doc, buffer);
  Serial.print(String(buffer));

  client.publish(mqtt_topic, buffer, true);
}
```

Then after an entry (peoplecounter.ino line 295) you can add these lines to publish the data.

```
        if ((PathTrack[1] == 1)  && (PathTrack[2] == 3) && (PathTrack[3] == 2)) {
          // this is an entry
          Passage_Event = "entry";
          LocalPeopleCount++;
          publishData();
          }
```
You can use the same method for for the exit event and distance measuring.

And an example of the JSON data can consequently look like this.

```
{"passage_event":"entry",
"distance":{"zone":1,"measurement":2115}
"local_people_count":1}
```

Maybe I'm completely wrong and does this change only make things more difficult. Also it depends on how the users use the code of course. Anyway, it's just a suggestion. If it would help I can also share my 'version' of your code, where I did some stuff different. (Using a cheap aliexpress time of flight sensor which has a different I2C address.)

AhmedFaizaan, 2022-01-31:
could you share your code? i am interested.

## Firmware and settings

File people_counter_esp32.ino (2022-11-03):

#include <Wire.h>
#include "SparkFun_VL53L1X.h"
#include <WiFi.h>
#include <PubSubClient.h>
#include <ESPmDNS.h>
#include <WiFiUdp.h>
#include <ArduinoOTA.h>
#include <EEPROM.h>

const char* devicename = "name_of_the_device"; // sets MQTT topics and hostname for ArduinoOTA

const char* ssid = "";     //wi-fi netwrok name
const char* password = "";  //wi-fi network password
const char* mqtt_server = "";   // mqtt broker ip address (without port)
const int mqtt_port = 0;                   // mqtt broker port
const char *mqtt_user = "";
const char *mqtt_pass = "";

// MQTT Topics
// people_counter/DEVICENAME/counter
// people_counter/DEVICENAME/distance
// people_counter/DEVICENAME/receiver

const int threshold_percentage = 80;

// if "true", the raw measurements are sent via MQTT during runtime (for debugging) - I'd recommend setting it to "false" to save traffic and system resources.
// in the calibration phase the raw measurements will still be sent through MQTT
static bool update_raw_measurements = true;

// this value has to be true if the sensor is oriented as in Duthdeffy's picture
static bool advised_orientation_of_the_sensor = true;

// this value has to be true if you don't need to compute the threshold every time the device is turned on
static bool save_calibration_result = true;


// parameters which define the time between two different measurements in longRange mode
static int delay_between_measurements_long = 55;
static int time_budget_in_ms_long = 50;

// parameters which define the time between two different measurements in longRange mode
static int time_budget_in_ms_short = 20;
static int delay_between_measurements_short = 22;

// value which defines the threshold which activates the short distance mode (the sensor supports it only up to a distance of 1300 mm)
static int short_distance_threshold = 1300;


//*******************************************************************************************************************
// all the code from this point and onwards doesn't have to be touched in order to have everything working (hopefully)

char mqtt_serial_publish_ch_cache[50];
char mqtt_serial_publish_distance_ch_cache[50];
char mqtt_serial_receiver_ch_cache[50];

int mqtt_counter = sprintf(mqtt_serial_publish_ch_cache,"%s%s%s","people_counter/", devicename,"/counter");
const PROGMEM char* mqtt_serial_publish_ch = mqtt_serial_publish_ch_cache;
int mqtt_distance = sprintf(mqtt_serial_publish_distance_ch_cache,"%s%s%s","people_counter/", devicename,"/distance");
const PROGMEM char* mqtt_serial_publish_distance_ch = mqtt_serial_publish_distance_ch_cache;
int mqtt_receiver = sprintf(mqtt_serial_receiver_ch_cache,"%s%s%s","people_counter/", devicename,"/receiver");
const PROGMEM char* mqtt_serial_receiver_ch = mqtt_serial_receiver_ch_cache;

#define EEPROM_SIZE 8

WiFiClient espClient;
PubSubClient client(espClient);

char peopleCounterArray[50];
//Optional interrupt and shutdown pins.  Vanno cambiati e messi quelli che hanno i collegamenti i^2C
#define SHUTDOWN_PIN 2    
#define INTERRUPT_PIN 3

SFEVL53L1X distanceSensor(Wire);//, SHUTDOWN_PIN, INTERRUPT_PIN);

static int NOBODY = 0;
static int SOMEONE = 1;
static int LEFT = 0;
static int RIGHT = 1;

static int DIST_THRESHOLD_MAX[] = {0, 0};   // treshold of the two zones
static int MIN_DISTANCE[] = {0, 0};

static int PathTrack[] = {0,0,0,0};
static int PathTrackFillingSize = 1; // init this to 1 as we start from state where nobody is any of the zones
static int LeftPreviousStatus = NOBODY;
static int RightPreviousStatus = NOBODY;

static int center[2] = {0,0}; /* center of the two zones */  
static int Zone = 0;
static int PplCounter = 0;

static int ROI_height = 0;
static int ROI_width = 0;

static int delay_between_measurements = 0;
static int time_budget_in_ms = 0;


void zones_calibration_boot(){
  if (save_calibration_result){
    // if possible, we take the old values of the zones contained in the EEPROM memory
    client.publish(mqtt_serial_publish_distance_ch, "save calibration result true");
    if (EEPROM.read(0) == 1){
      // we have data in the EEPROM
      client.publish(mqtt_serial_publish_distance_ch, "EEPROM memroy not empty");
      center[0] = EEPROM.read(1);
      center[1] = EEPROM.read(2);
      ROI_height = EEPROM.read(3);
      ROI_width = EEPROM.read(3);
      DIST_THRESHOLD_MAX[0] = EEPROM.read(4)*100 + EEPROM.read(5);
      DIST_THRESHOLD_MAX[1] = EEPROM.read(6)*100 + EEPROM.read(7);

      // if the distance measured is small, then we can use the short range mode of the sensor
      if (min(DIST_THRESHOLD_MAX[0], DIST_THRESHOLD_MAX[1]) <= short_distance_threshold){
        distanceSensor.setIntermeasurementPeriod(time_budget_in_ms_short);
        distanceSensor.setDistanceModeShort();
        time_budget_in_ms = time_budget_in_ms_short;
        delay_between_measurements = delay_between_measurements_short;
      }
      else {
        distanceSensor.setIntermeasurementPeriod(time_budget_in_ms_long);
        distanceSensor.setDistanceModeLong();
        time_budget_in_ms = time_budget_in_ms_long;
        delay_between_measurements = delay_between_measurements_long;
      }
      publishDistance(center[0], 0);
      publishDistance(center[1], 0);
      publishDistance(ROI_width, 0);
      publishDistance(ROI_height, 0);
      publishDistance(DIST_THRESHOLD_MAX[0], 0);
      publishDistance(DIST_THRESHOLD_MAX[1], 0);
      client.publish(mqtt_serial_publish_distance_ch, "All values updated");
    }
    else{
      // there are no data in the EEPROM memory
      zones_calibration();
    }
  }
  else
    zones_calibration();
}

void zones_calibration(){
  // the sensor does 100 measurements for each zone (zones are predefined)
  // each measurements is done with a timing budget of 100 ms, to increase the precision
  client.publish(mqtt_serial_publish_distance_ch, "Computation of new threshold");
  // we set the standard values for the measurements
  distanceSensor.setIntermeasurementPeriod(time_budget_in_ms_long);
  distanceSensor.setDistanceModeLong();
  time_budget_in_ms = time_budget_in_ms_long;
  delay_between_measurements = delay_between_measurements_long;
  center[0] = 167;
  center[1] = 231;
  ROI_height = 8;
  ROI_width = 8;
  delay(500);
  
  Zone = 0;
  float sum_zone_0 = 0;
  float sum_zone_1 = 0;
  uint16_t distance;
  int number_attempts = 20;
  for (int i=0; i<number_attempts; i++){
      // increase sum of values in Zone 0
      distanceSensor.setROI(ROI_height, ROI_width, center[Zone]);  // first value: height of the zone, second value: width of the zone
      delay(delay_between_measurements);
      distanceSensor.setTimingBudgetInMs(time_budget_in_ms);
      distanceSensor.startRanging(); //Write configuration bytes to initiate measurement
      distance = distanceSensor.getDistance(); //Get the result of the measurement from the sensor
      distanceSensor.stopRanging();      
      sum_zone_0 = sum_zone_0 + distance;
      publishDistance(distance, 0);
      Zone++;
      Zone = Zone%2;

      // increase sum of values in Zone 1
      distanceSensor.setROI(ROI_height, ROI_width, center[Zone]);  // first value: height of the zone, second value: width of the zone
      delay(delay_between_measurements);
      distanceSensor.setTimingBudgetInMs(time_budget_in_ms);
      distanceSensor.startRanging(); //Write configuration bytes to initiate measurement
      distance = distanceSensor.getDistance(); //Get the result of the measurement from the sensor
      distanceSensor.stopRanging();      
      sum_zone_1 = sum_zone_1 + distance;
      publishDistance(distance, 1);
      Zone++;
      Zone = Zone%2;
  }
  // after we have computed the sum for each zone, we can compute the average distance of each zone
  float average_zone_0 = sum_zone_0 / number_attempts;
  float average_zone_1 = sum_zone_1 / number_attempts;
  // the value of the average distance is used for computing the optimal size of the ROI and consequently also the center of the two zones
  int function_of_the_distance = 16*(1 - (0.15 * 2) / (0.34 * (min(average_zone_0, average_zone_1)/1000) ));
  publishDistance(function_of_the_distance, 1);
  delay(1000);
  int ROI_size = min(8, max(4, function_of_the_distance));
  ROI_width = ROI_size;
  ROI_height = ROI_size;
  if (average_zone_0 <= short_distance_threshold  || average_zone_1 <= short_distance_threshold )
  {
      // we can use the short mode, which allows more precise measurements up to 1.3 meters
      distanceSensor.setIntermeasurementPeriod(time_budget_in_ms_short);
      distanceSensor.setDistanceModeShort();
      time_budget_in_ms = time_budget_in_ms_short;
      delay_between_measurements = delay_between_measurements_short;
  }
  delay(250);

  // now we set the position of the center of the two zones
  if (advised_orientation_of_the_sensor){
    
    switch (ROI_size) {
        case 4:
          center[0] = 150;
          center[1] = 247;
          break;
        case 5:
          center[0] = 159;
          center[1] = 239;
          break;
        case 6:
          center[0] = 159;
          center[1] = 239;
          break;
        case 7:
          center[0] = 167;
          center[1] = 231;
          break;
        case 8:
          center[0] = 167;
          center[1] = 231;
          break;
      }
  }
  else{
    switch (ROI_size) {
        case 4:
          center[0] = 193;
          center[1] = 58;
           break;
        case 5:
          center[0] = 194;
          center[1] = 59;
          break;
        case 6:
          center[0] = 194;
          center[1] = 59;
          break;
        case 7:
          center[0] = 195;
          center[1] = 60;
          break;
        case 8:
          center[0] = 195;
          center[1] = 60;
          break;
      }
  }
  client.publish(mqtt_serial_publish_distance_ch, "ROI size");
  publishDistance(ROI_size, 0);  
  client.publish(mqtt_serial_publish_distance_ch, "centers of the ROIs defined");
  publishDistance(center[0], 0);   
  publishDistance(center[1], 1);
  delay(2000);
  // we will now repeat the calculations necessary to define the thresholds with the updated zones
  Zone = 0;
  sum_zone_0 = 0;
  sum_zone_1 = 0;
  for (int i=0; i<number_attempts; i++){
      // increase sum of values in Zone 0
      distanceSensor.setROI(ROI_height, ROI_width, center[Zone]);  // first value: height of the zone, second value: width of the zone
      delay(delay_between_measurements);
      distanceSensor.setTimingBudgetInMs(time_budget_in_ms);
      distanceSensor.startRanging(); //Write configuration bytes to initiate measurement
      distance = distanceSensor.getDistance(); //Get the result of the measurement from the sensor
      distanceSensor.stopRanging();      
      sum_zone_0 = sum_zone_0 + distance;
      publishDistance(distance, 0);
      Zone++;
      Zone = Zone%2;

      // increase sum of values in Zone 1
      distanceSensor.setROI(ROI_height, ROI_width, center[Zone]);  // first value: height of the zone, second value: width of the zone
      delay(delay_between_measurements);
      distanceSensor.setTimingBudgetInMs(time_budget_in_ms);
      distanceSensor.startRanging(); //Write configuration bytes to initiate measurement
      distance = distanceSensor.getDistance(); //Get the result of the measurement from the sensor
      distanceSensor.stopRanging();      
      sum_zone_1 = sum_zone_1 + distance;
      publishDistance(distance, 1);
      Zone++;
      Zone = Zone%2;
  }
  average_zone_0 = sum_zone_0 / number_attempts;
  average_zone_1 = sum_zone_1 / number_attempts;
  float threshold_zone_0 = average_zone_0 * threshold_percentage/100; // they can be int values, as we are not interested in the decimal part when defining the threshold
  float threshold_zone_1 = average_zone_1 * threshold_percentage/100;
  
  DIST_THRESHOLD_MAX[0] = threshold_zone_0;
  DIST_THRESHOLD_MAX[1] = threshold_zone_1;
  client.publish(mqtt_serial_publish_distance_ch, "new threshold defined");
  publishDistance(threshold_zone_0, 0);   
  publishDistance(threshold_zone_1, 1);
  delay(2000);

  // we now save the values into the EEPROM memory
  int hundred_threshold_zone_0 = threshold_zone_0 / 100;
  int hundred_threshold_zone_1 = threshold_zone_1 / 100;
  int unit_threshold_zone_0 = threshold_zone_0 - 100* hundred_threshold_zone_0;
  int unit_threshold_zone_1 = threshold_zone_1 - 100* hundred_threshold_zone_1;

  EEPROM.write(0, 1);
  EEPROM.write(1, center[0]);
  EEPROM.write(2, center[1]);
  EEPROM.write(3, ROI_size);
  EEPROM.write(4, hundred_threshold_zone_0);
  EEPROM.write(5, unit_threshold_zone_0);
  EEPROM.write(6, hundred_threshold_zone_1);
  EEPROM.write(7, unit_threshold_zone_1);
  EEPROM.commit();
  
}


void setup_wifi() 
{
  WiFi.begin(ssid, password);
  while (WiFi.status() != WL_CONNECTED) 
  {
    delay(500);
    Serial.print(".");
    WiFi.begin(ssid, password);     // as suggested by @LC7894 in #23, deleting this line might solve sime issues
  }
}

void callback(char* topic, byte *payload, unsigned int length) {
    Serial.println("-------new message from broker-----");
    Serial.print("channel:");
    Serial.println(topic);
    Serial.print("data:");  
    Serial.write(payload, length);
    Serial.println();
    String newTopic = topic;
    payload[length] = '\0';
    String newPayload = String((char *)payload);    
    if (newTopic == mqtt_serial_receiver_ch) 
    {
      if (newPayload == "zones_calibration")
      {
        zones_calibration();
      }
      if (newPayload == "update_raw_measurements")
      {
        if (update_raw_measurements)
        {
          // it is true, then it is going to be changed to false
          update_raw_measurements = false;
        }
        else
        {
          update_raw_measurements = true;
        }
        delay(200);
      }
    }
}

void reconnect() {
  // Loop until we're reconnected
  while (!client.connected()) {
    Serial.print("Attempting MQTT connection...");
    // Create a random client ID
    String clientId = "ESP32Client-";
    clientId += String(random(0xffff), HEX);
    // Attempt to connect
    if (client.connect(clientId.c_str(),mqtt_user,mqtt_pass)) {
      Serial.println("connected");
      client.subscribe(mqtt_serial_receiver_ch);
    } else {
      Serial.print("failed, rc=");
      Serial.print(client.state());
      Serial.println(" try again in 5 seconds");
      // Wait 5 seconds before retrying
      delay(5000);
    }
  }
}




void publishPersonPassage(int serialData){
  serialData = max(0, serialData);
  if (!client.connected()) {
    reconnect();
  }
  String stringaCounter = String(serialData);
  stringaCounter.toCharArray(peopleCounterArray, stringaCounter.length() +1);
  client.publish(mqtt_serial_publish_ch, peopleCounterArray);
}

void publishDistance(int serialData, int zona){
  //serialData = max(0, serialData);
  if (!client.connected()) {
    reconnect();
  }
  String stringaZona = "\t zona = ";
  String stringaCounter = String(serialData)+ stringaZona + String(zona) + "\t" + String(PathTrack[0]) + String(PathTrack[1]) + String(PathTrack[2]) +String(PathTrack[3]);
  stringaCounter.toCharArray(peopleCounterArray, stringaCounter.length() +1);
  client.publish(mqtt_serial_publish_distance_ch, peopleCounterArray);
}

void setup(void)
{
  Wire.begin();
  // initialize the EEPROM memory
  EEPROM.begin(EEPROM_SIZE);
  
  Serial.begin(9600);
  Serial.println("VL53L1X Qwiic Test");

  if (distanceSensor.init() == false)
    Serial.println("Sensor online!");

  Serial.setTimeout(200);// Set time out for setup_wifi();
  setup_wifi();
  client.setServer(mqtt_server, mqtt_port);
  client.setCallback(callback);
  delay(1000);
  zones_calibration_boot();
  reconnect();  
  
  ArduinoOTA
    .onStart([]() {
      String type;
      if (ArduinoOTA.getCommand() == U_FLASH)
        type = "sketch";
      else // U_SPIFFS
        type = "filesystem";

      // NOTE: if updating SPIFFS this would be the place to unmount SPIFFS using SPIFFS.end()
      Serial.println("Start updating " + type);
    })
    .onEnd([]() {
      Serial.println("\nEnd");
    })
    .onProgress([](unsigned int progress, unsigned int total) {
      Serial.printf("Progress: %u%%\r", (progress / (total / 100)));
    })
    .onError([](ota_error_t error) {
      Serial.printf("Error[%u]: ", error);
      if (error == OTA_AUTH_ERROR) Serial.println("Auth Failed");
      else if (error == OTA_BEGIN_ERROR) Serial.println("Begin Failed");
      else if (error == OTA_CONNECT_ERROR) Serial.println("Connect Failed");
      else if (error == OTA_RECEIVE_ERROR) Serial.println("Receive Failed");
      else if (error == OTA_END_ERROR) Serial.println("End Failed");
    });
  ArduinoOTA.setHostname(devicename);
  ArduinoOTA.begin();

  Serial.println("Ready");
  Serial.print("IP address: ");
  Serial.println(WiFi.localIP());
}



void loop(void)
{
  ArduinoOTA.handle();
  uint16_t distance;
  client.loop();
  if (!client.connected()) 
  {
    reconnect();
  }
  
  
  distanceSensor.setROI(ROI_height, ROI_width, center[Zone]);  // first value: height of the zone, second value: width of the zone
  delay(delay_between_measurements);
  distanceSensor.setTimingBudgetInMs(time_budget_in_ms);
  distanceSensor.startRanging(); //Write configuration bytes to initiate measurement
  distance = distanceSensor.getDistance(); //Get the result of the measurement from the sensor
  distanceSensor.clearInterrupt();
  distanceSensor.stopRanging();

  Serial.println(distance);
  if(update_raw_measurements == true) {
    publishDistance(distance, Zone);
  }

   // inject the new ranged distance in the people counting algorithm
  processPeopleCountingData(distance, Zone);

  Zone++;
  Zone = Zone%2;


}

// NOBODY = 0, SOMEONE = 1, LEFT = 0, RIGHT = 1

void processPeopleCountingData(int16_t Distance, uint8_t zone) {

    int CurrentZoneStatus = NOBODY;
    int AllZonesCurrentStatus = 0;
    int AnEventHasOccured = 0;

  if (Distance < DIST_THRESHOLD_MAX[Zone] && Distance > MIN_DISTANCE[Zone]) {
    // Someone is in !
    CurrentZoneStatus = SOMEONE;
  }

  // left zone
  if (zone == LEFT) {

    if (CurrentZoneStatus != LeftPreviousStatus) {
      // event in left zone has occured
      AnEventHasOccured = 1;

      if (CurrentZoneStatus == SOMEONE) {
        AllZonesCurrentStatus += 1;
      }
      // need to check right zone as well ...
      if (RightPreviousStatus == SOMEONE) {
        // event in left zone has occured
        AllZonesCurrentStatus += 2;
      }
      // remember for next time
      LeftPreviousStatus = CurrentZoneStatus;
    }
  }
  // right zone
  else {

    if (CurrentZoneStatus != RightPreviousStatus) {

      // event in left zone has occured
      AnEventHasOccured = 1;
      if (CurrentZoneStatus == SOMEONE) {
        AllZonesCurrentStatus += 2;
      }
      // need to left right zone as well ...
      if (LeftPreviousStatus == SOMEONE) {
        // event in left zone has occured
        AllZonesCurrentStatus += 1;
      }
      // remember for next time
      RightPreviousStatus = CurrentZoneStatus;
    }
  }

  // if an event has occured
  if (AnEventHasOccured) {
    if (PathTrackFillingSize < 4) {
      PathTrackFillingSize ++;
    }

    // if nobody anywhere lets check if an exit or entry has happened
    if ((LeftPreviousStatus == NOBODY) && (RightPreviousStatus == NOBODY)) {

      // check exit or entry only if PathTrackFillingSize is 4 (for example 0 1 3 2) and last event is 0 (nobobdy anywhere)
      if (PathTrackFillingSize == 4) {
        // check exit or entry. no need to check PathTrack[0] == 0 , it is always the case
        Serial.println();
        if ((PathTrack[1] == 1)  && (PathTrack[2] == 3) && (PathTrack[3] == 2)) {
          // this is an entry
          publishPersonPassage(1);
        } else if ((PathTrack[1] == 2)  && (PathTrack[2] == 3) && (PathTrack[3] == 1)) {
          // This an exit
          publishPersonPassage(2);
          }
      }
      for (int i=0; i<4; i++){
        PathTrack[i] = 0;
      }
      PathTrackFillingSize = 1;
    }
    else {
      // update PathTrack
      // example of PathTrack update
      // 0
      // 0 1
      // 0 1 3
      // 0 1 3 1
      // 0 1 3 3
      // 0 1 3 2 ==> if next is 0 : check if exit
      PathTrack[PathTrackFillingSize-1] = AllZonesCurrentStatus;
    }
  }
}

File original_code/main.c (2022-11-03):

/**
  ******************************************************************************
  * File Name          : main.c
  * Description        : Main program body
  ******************************************************************************
  *
  * COPYRIGHT(c) 2017 STMicroelectronics
  *
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
  ******************************************************************************
  */
	
/* Includes ------------------------------------------------------------------*/
#include "stm32xxx_hal.h"

/* USER CODE BEGIN Includes */
#include "main.h"
#include "VL53L1X_API.h"
#include "VL53l1X_calibration.h"
#include "X-NUCLEO-53L1A1.h"
/* USER CODE END Includes */
/* USER CODE BEGIN PV */
I2C_HandleTypeDef hi2c1;
UART_HandleTypeDef huart2;
uint16_t	dev=0x52;
int status = 0;
volatile int IntCount;
#define isInterrupt 1 /* If isInterrupt = 1 then device working in interrupt mode, else device working in polling mode */
/* USER CODE END PV */

/* USER CODE BEGIN PFP */
int SystemClock_Config(void);
static void MX_GPIO_Init(void);
static int MX_USART2_UART_Init(void);
static int MX_I2C1_Init(void);
/* USER CODE END PFP */

/* USER CODE BEGIN 0 */
#define PUTCHAR_PROTOTYPE int fputc(int ch, FILE *f)

// People Counting defines
#define NOBODY 0
#define SOMEONE 1
#define LEFT 0
#define RIGHT 1

#define DIST_THRESHOLD_MAX  1780


PUTCHAR_PROTOTYPE
{
	HAL_UART_Transmit(&huart2, (uint8_t*)&ch, 1, 0xFFFF);
	return ch;
}

void HAL_GPIO_EXTI_Callback(uint16_t GPIO_Pin)
{
	if (GPIO_Pin==VL53L1X_INT_Pin)
	{
		IntCount++;
	}
}

/* USER CODE END 0 */



int ProcessPeopleCountingData(int16_t Distance, uint8_t zone) {
    static int PathTrack[] = {0,0,0,0};
    static int PathTrackFillingSize = 1; // init this to 1 as we start from state where nobody is any of the zones
    static int LeftPreviousStatus = NOBODY;
    static int RightPreviousStatus = NOBODY;
    static int PeopleCount = 0;

    int CurrentZoneStatus = NOBODY;
    int AllZonesCurrentStatus = 0;
    int AnEventHasOccured = 0;

	if (Distance < DIST_THRESHOLD_MAX) {
		// Someone is in !
		CurrentZoneStatus = SOMEONE;
	}

	// left zone
	if (zone == LEFT) {

		if (CurrentZoneStatus != LeftPreviousStatus) {
			// event in left zone has occured
			AnEventHasOccured = 1;

			if (CurrentZoneStatus == SOMEONE) {
				AllZonesCurrentStatus += 1;
			}
			// need to check right zone as well ...
			if (RightPreviousStatus == SOMEONE) {
				// event in left zone has occured
				AllZonesCurrentStatus += 2;
			}
			// remember for next time
			LeftPreviousStatus = CurrentZoneStatus;
		}
	}
	// right zone
	else {

		if (CurrentZoneStatus != RightPreviousStatus) {

			// event in left zone has occured
			AnEventHasOccured = 1;
			if (CurrentZoneStatus == SOMEONE) {
				AllZonesCurrentStatus += 2;
			}
			// need to left right zone as well ...
			if (LeftPreviousStatus == SOMEONE) {
				// event in left zone has occured
				AllZonesCurrentStatus += 1;
			}
			// remember for next time
			RightPreviousStatus = CurrentZoneStatus;
		}
	}

	// if an event has occured
	if (AnEventHasOccured) {
		if (PathTrackFillingSize < 4) {
			PathTrackFillingSize ++;
		}

		// if nobody anywhere lets check if an exit or entry has happened
		if ((LeftPreviousStatus == NOBODY) && (RightPreviousStatus == NOBODY)) {

			// check exit or entry only if PathTrackFillingSize is 4 (for example 0 1 3 2) and last event is 0 (nobobdy anywhere)
			if (PathTrackFillingSize == 4) {
				// check exit or entry. no need to check PathTrack[0] == 0 , it is always the case

				if ((PathTrack[1] == 1)  && (PathTrack[2] == 3) && (PathTrack[3] == 2)) {
					// This an entry
					PeopleCount ++;

				} else if ((PathTrack[1] == 2)  && (PathTrack[2] == 3) && (PathTrack[3] == 1)) {
					// This an exit
					PeopleCount --;
				}
			}

			PathTrackFillingSize = 1;
		}
		else {
			// update PathTrack
			// example of PathTrack update
			// 0
			// 0 1
			// 0 1 3
			// 0 1 3 1
			// 0 1 3 3
			// 0 1 3 2 ==> if next is 0 : check if exit
			PathTrack[PathTrackFillingSize-1] = AllZonesCurrentStatus;
		}
	}

	// output debug data to main host machine
	return(PeopleCount);

}

int main(void)
{
	int8_t error;
    uint8_t byteData, sensorState=0;
    uint16_t wordData;
    uint16_t Distance;
    uint8_t RangeStatus;
    uint8_t dataReady;
    int center[2] = {167,231}; /* these are the spad center of the 2 8*16 zones */
    int Zone = 0;
    int PplCounter = 0;

    /* MCU Configuration----------------------------------------------------------*/

    /* Reset of all peripherals, Initializes the Flash interface and the Systick. */
    HAL_Init();

    /* Configure the system clock */
    error = SystemClock_Config();

    /* Initialize all configured peripherals */
     MX_GPIO_Init();
    error += MX_USART2_UART_Init();
    error += MX_I2C1_Init();

    if (error != 0)
    {
        printf("Could not initialize the nucleo board\n");
        return -1;
    }

    status = XNUCLEO53L1A1_Init();
		printf("XNUCLEO53L1A1_Init Status : %X\n", status);


    status = XNUCLEO53L1A1_ResetId(XNUCLEO53L1A1_DEV_LEFT, 0); // Reset ToF sensor
    HAL_Delay(2);
    status = XNUCLEO53L1A1_ResetId(XNUCLEO53L1A1_DEV_CENTER, 0); // Reset ToF sensor
    HAL_Delay(2);
    status = XNUCLEO53L1A1_ResetId(XNUCLEO53L1A1_DEV_RIGHT, 0); // Reset ToF sensor
    HAL_Delay(2);
    status = XNUCLEO53L1A1_ResetId(XNUCLEO53L1A1_DEV_LEFT, 1); // Reset ToF sensor
    HAL_Delay(2);

    // Those basic I2C read functions can be used to check your own I2C functions */
    status = VL53L1_RdByte(dev, 0x010F, &byteData);
    printf("VL53L1X Model_ID: %X\n", byteData);
    status = VL53L1_RdByte(dev, 0x0110, &byteData);
    printf("VL53L1X Module_Type: %X\n", byteData);
    status = VL53L1_RdWord(dev, 0x010F, &wordData);
    printf("VL53L1X: %X\n", wordData);
    while (sensorState == 0) {
        status = VL53L1X_BootState(dev, &sensorState);
        HAL_Delay(2);
    }

    printf("Chip booted\n");

    /* Initialize and configure the device according to people counting need */
    status = VL53L1X_SensorInit(dev);
    status += VL53L1X_SetDistanceMode(dev, 2); /* 1=short, 2=long */
    status += VL53L1X_SetTimingBudgetInMs(dev, 20); /* in ms possible values [20, 50, 100, 200, 500] */
    status += VL53L1X_SetInterMeasurementInMs(dev, 20);
    status += VL53L1X_SetROI(dev, 8, 16); /* minimum ROI 4,4 */
    if (status != 0) {
        printf("Error in Initialization or configuration of the device\n");
        return (-1);
    }

    printf("Start counting people  ...\n");
    status = VL53L1X_StartRanging(dev);   /* This function has to be called to enable the ranging */

    while(1) { /* read and display data */
        while (dataReady == 0) {
			status = VL53L1X_CheckForDataReady(dev, &dataReady);
			HAL_Delay(2);
        }
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

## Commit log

2020-11-19 Minor changes to the code
    Deletion of some lines that produced an error when compiling
    [peopleCounterOTA.ino]
2020-11-20 Update peopleCounter.ino
    Eliminated some lines of code that produced an error
    [peopleCounter.ino]
2020-11-20 Update peopleCounterOTA.ino
    Eliminated some lines that produced an error
    [peopleCounterOTA.ino]
2020-11-26 Create peopleCounterESP8266.ino
    Code specific for ESP8266 device
2021-01-17 Update peopleCounter.ino
    Eliminated issue that created wrong output
    [peopleCounter.ino]
2021-01-17 Update peopleCounterESP8266.ino
    Eliminated issue which produced wrong output
    [peopleCounterESP8266.ino]
2021-02-03 Eliminated the second message in MQTT
    Thanks to @daniele-athome for the suggestion of this modification that avoids creating a sensor in Home Assistant
    [peopleCounterESP8266.ino]
2021-02-03 Elimination of a sensor
    Eliminated the creation of an additional sensor in Home Assistant
2021-02-25 New code for ESP8266
    Hey, since I have an ESP8266 I tried to adapt the code. I changed some libraries and did minor changes to the code (WiFi setup and OTA update). There might still be some mistakes since I just have a basic knowledge about Arduino programming, but I tested this version on my ESP and it works 🙂
2021-03-27 Added shortMode distance support
    Now, whenever the distance in both zones is below 1300 mm (this value can be changed) the sensors starts measuring using the Short distance mode, which allows for more frequent measurements
    [people_counter_esp32.ino]

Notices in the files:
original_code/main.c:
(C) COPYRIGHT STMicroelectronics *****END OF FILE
